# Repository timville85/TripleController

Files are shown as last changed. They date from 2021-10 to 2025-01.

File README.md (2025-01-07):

# 3dapter (formerly Triple Controller to USB)

This project combines the NES, SNES and Genesis DaemonBite Retro Controllers projects together with a custom PCB to support 3 different controllers with a single socketed Arduino Pro Micro. PCB (KiCad + Gerbers), 3D Cases, and muliple firmware versions (Arduino code) all available in this repository.

PCB Kits + Fully Assembled units (with firmware of your choice) available on [Tindie](https://www.tindie.com/products/24994/)

3 different firmware versions are available in this repo:
* Default: Optimized for MiSTer, PC, Raspberry Pi, etc. - reports as 3 separate controllers, supports multiplayer from a single unit.
* Analogue Pocket: Optimized for Pocket Dock - reports as a single wired XInput device.
* Nintendo Switch: Optimized for Nintendo Switch Online NES, SNES, and Genesis collections - reports as a single wired switch controller.

**Looking for a version with a N64 port? Check out the** [4dapter](https://github.com/timville85/4dapter)

## Resources Used

* [DaemonBite Retro Controllers](https://github.com/MickGyver/DaemonBite-Retro-Controllers-USB)
* https://github.com/esden/pretty-kicad-libs
* https://github.com/ddribin/nes-port-breadboard
* https://github.com/Biacco42/ProMicroKiCad
* http://www.neshq.com/hardgen/powerpad.txt

## 3D Case Files

3D Case files were designed by [Dinierto Designs](https://www.etsy.com/shop/DiniertoDesigns) and are available on [Thingiverse](https://www.thingiverse.com/thing:5011783)

3D Case Size Reference:
* 33mm - Most Micro USB Pro Micro / Sparkfun USB-C Pro Micro boards
* 35-36mm - Most AliExpress USB-C Pro Micro boards
* 36-37mm - Some AliExpress USB-C Pro Micro boards (typically with empty hole next to USB-C port)

## Wiring Diagram

TripleController-V2 1-Layout

Current Draw Readings from DIO Pin 16 (used for 5v supply for DB9 port):
* Krikzz Joyzz:	38mA
* 8BitDo M30 2.4G: 29mA
* OEM SEGA 3-Button Wired: 3mA
* OEM SEGA 6-Button Wired: 3mA
* Retrobit 6-Button Wired: 2mA
(Arduino DIO Max Rated Current: 40mA)

## Tested Controllers

The following controllers have been personally tested and are supported with the Triple Controller. All listed devices also fit when using the 3D Case as well.

NES:
* OEM NES Controller
* OEM NES PowerPad (Default FW Only)
* 8BitDo N30 2.4G Receiver
* 8BitDo NES Retro Receiver

SEGA / Genesis:
* OEM SEGA Master System 2-Button Controller
* OEM Genesis 3-Button Controller
* OEM Genesis 6-Button Controller
* 8BitDo M30 2.4G Receiver
* 8BitDo Genesis Retro Receiver
* Krikzz Joyzz

SNES:
* OEM SNES Controller
* OEM SFC Controller
* OEM SNES NTT Controller (Default FW Only)
* 8BitDo SN30 2.4G Receiver
* 8BitDo SNES Retro Receiver

## Bill of Materials
* **3dapter / Triple Controller PCB**

* **1x SNES Socket (90 deg):** [AliExpress - Gamers Zone Store](https://www.aliexpress.com/item/32838396935.html) 

* **1x NES Socket:** [AliExpress - Gamers Zone Store](https://www.aliexpress.com/item/1005003699734963.html)

* **1x Genesis Socket:** [AliExpress - Gamers Zone Store](https://www.aliexpress.com/item/1005003699497865.html)

* **Micro USB Arduino Pro Micro (reinforced USB port):** [Amazon](https://www.amazon.com/gp/product/B01HCXMBOU/) *(Pack of 3)*

* **1x Arduino Pro Micro (USB-C 3-15V Version):** [AliExpress](https://www.aliexpress.us/item/2251832700923799.html)

* **2x 1x12 Female Header:** [Digi-Key](https://www.digikey.com/en/products/detail/sullins-connector-solutions/PPTC121LFBN-RC/807231)

## PCB + Assembled Examples

unassembled

built

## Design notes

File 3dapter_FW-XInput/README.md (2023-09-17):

# 3dapter - XInput / Analogue Pocket Dock Firmware

This alternative firmware will allow the 3dapter (Triple Controller) to appear a single XInput controller. All 3 controller inputs will share the same singular player input (i.e. use only one controller at time). 

The controller inputs have been mapped to align with the default mapping on the Analogue Pocket Dock (as of firmware 1.1).

"Home" Button is supported on each controller type to bring up the Analogue Dock menu:
* NES: `Select + Down`
* SNES: `Select + Down`
* Genesis: `Mode + Down` (or 8BitDo M30 'Heart' button)

## IMPORTANT NOTE
**Installing the XInput Library will remove the self-reset listener from the Arduino board. This means you will need to manually reset the Arduino when updating the code on the board or switching to a different firmware.**

**You can accomplish this by connecting the RST and GND pins together - a tip of a screwdriver works well since the pins are next to each other.**



### Resources Used

* https://github.com/dmadison/ArduinoXInput
* https://github.com/dmadison/ArduinoXInput_AVR

## Install Instructions

**Instructions tested with Arduino 1.8.19 - not fully tested with Arduino 2.X!**

### 1. Install XInput Library (tested with 1.2.6) from Arduino Library Manager



### 2. Add the following URL as an Additional Board Manager URL (in File -> Preferences menu)

`https://raw.githubusercontent.com/dmadison/ArduinoXInput_Boards/master/package_dmadison_xinput_index.json`



### 3. Install XInput AVR Boards (tested with 1.0.5) from Arduino Boards Manager

_Note: Choose the AVR version, not Sparkfun_



### 4. Select "XInput AVR Boards - Arduino Leonardo w/ XInput" from Boards List



### 5. Download project to Arduino Pro Micro board

Remember after download your Arduino Pro Micro will no longer report as a Serial device and will not appear in the "Port" list in the Arduino software.

Note: If you are replacing existing code on the 3dapter, trigger the download from the Arduino software and then trigger a reset on the Arduino Pro Micro within a few seconds of starting the download. If the download fails initially due to not finding the COM port, repeat the download/reset process and it should work the second time.

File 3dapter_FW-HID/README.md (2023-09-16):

# 3dapter - HID Firmware for MiSTer / PC

The default HID firmware will allow the 3dapter (Triple Controller) to appear a multiplayer input controller with each controller input acting as it's own separate player/input.

## Controller Button Mapping

To maintain proper button mapping on MiSTer, it's recommended to map the SNES controller on the MiSTer Main menu and the NES / Genesis controllers will align to their core defaults properly.

```
Button   NES        SNES       GENESIS (normal)    GENESIS (MiSTer)
-------------------------------------------------------------------
01       B          B          B                   A 
02       A          A          A                   B
03       N/A        Y          Y                   X
04       N/A        X          X                   Y
05       N/A        L          Z                   Z
06       N/A        R          C                   C
07       SELECT     SELECT     MODE                MODE
08       START      START      START               START
09       N/A        N/A        HOME (8BitDo)       (N/A but HOME will send MODE + DOWN)
```

## MiSTer Home Menu Suggestion
* **NES:** SELECT + DOWN
* **SNES:** SELECT + DOWN
* **GENESIS:** MODE + DOWN

*Note: SELECT + DOWN = HOME on 8BitDo N30*

## MiSTer mode on 8bitdo M30 controller

The 3dapter exposes three "players" on one USB device.  Unfortunately MiSTer does not support setting keymaps per "player", MiSTer mode works around this by making sure the positional mapping is the same between all controllers.

MiSTer mode can be toggled on and off with "HOME + Z" (you have to press HOME first, Z second). This setting is saved to EEPROM and preserved across power cycles. The default is "normal mode".

When the Genesis controller is in MiSTer mode:

- The HOME button sends "DOWN + MODE" (This is because no equivalent of the HOME button exists on the other controller ports)

- Buttons are swapped: A with B and X with Y. This is such that the position of the buttons is consistent between SNES and Genesis.

## Retroarch Port Binding

Some Retroarch users have reported issues regarding setting the correct “Device Index” setting, since the 3dapter reports a single “device” to RetroArch with 3 different controllers, each as their own “index”.

In Retroarch, go to Settings → Input → Port 1 Binds → Device Index and then choose #3 for DB9 and presumably #1 or #2 for NES and SNES. Save and it sticks for that game, core or content directory.

https://retropie.org.uk/forum/topic/26681/port-binds/
https://retropie.org.uk/docs/RetroArch-Configuration/#core-input-remapping

## Install Instructions

### 1. Select "Arduino AVR Boards - Arduino Leonardo" from Boards List

### 2. Download project to Arduino Pro Micro board

## Restoring Firmware After Alternative Firmware Downloads

If you previously used the Analogue Pocket or Nintendo Switch firmware versions, your Arduino Pro Micro will no longer report as a Serial device and will not appear in the "Port" list in the Arduino software. Using the default 3dapter firmware does not suffer from this issue.

To restore the default firmware for your Arduino Pro Micro, you will need to manually reset the Arduino Pro Micro by shorting the Reset + Ground pins together to trigger a reset. 

1. Open the default firmware project in the Arduino software.
2. Connect your Arduino Pro Micro to your computer.
3. Trigger the download from the Arduino software. The Arduino software will first compile the project before beginning the download.
4. Once the "compiling" step has finished, trigger a reset on the Arduino Pro Micro by briefly touching the Reset (RST) and Ground (GND) pins together. This should make the Arduino forcefully switch into bootloader mode and allow the download to complete. If the download fails initially due to not finding the COM port, repeat the download/reset process and it should work the second time.

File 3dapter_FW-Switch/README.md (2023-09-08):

# 3dapter - Nintendo Switch Firmware

This alternative firmware will allow the 3dapter (Triple Controller) to appear a single Switch-compatible controller. All 3 controller inputs will share the same singular player input (i.e. use only one controller at time). 

The controller inputs have been mapped to align to map to the Nintendo Switch Virtual NES, SNES, and Genesis apps. Switch-specific button combos have been added to support in-game menus, home buttons, and screenshot capabities.

## IMPORTANT NOTE
**Installing the XInput Library will remove the self-reset listener from the Arduino board. This means you will need to manually reset the Arduino when updating the code on the board or switching to a different firmware.**

**You can accomplish this by connecting the RST and GND pins together - a tip of a screwdriver works well since the pins are next to each other.**



## Switch Special Button Combos

NES:
* In-Game Menu ("-" Button): Select + D-Pad Down
* Home Button: Select + Start
* Screenshot: Select + Up

SNES:
* In-Game Menu ("-" Button): Select + D-Pad Down
* Home Button: Select + Start
* Screenshot: Select + Up

Genesis (6-Button):
* In-Game Menu ("-" Button): Mode + Down
* Home Button: Mode + Start (or 8BitDo M30 Heart Button)
* Screenshot: Mode + D-Pad Up

Genesis (3-Button):
* In-Game Menu ("-" Button): Start + A + B + C
* Home Button: Start + A + Down
* Screenshot: Start + A + Up

Input Toggle to swap D-Pad Input / Left Analog Joystick
* Hold Select/Mode + Down for 1.5 seconds
* Reports 8-Way Input (Cardinal + Diagonal)

Input Toggle to swap X / RB buttons
* Hold Mode + B for 1.5 Seconds
* Useful for games within the "Sega Genesis Classics" collection

## Resources Used

* [LUFA Arduino Board & Library](https://github.com/CrazyRedMachine/Arduino-Lufa)
* [Switch-Fightstick](https://github.com/progmem/Switch-Fightstick).

## Install Instructions

### 1. Add the following URL as an Additional Board Manager URL (in File -> Preferences menu)
`https://github.com/CrazyRedMachine/Arduino-Lufa/raw/master/package_arduino-lufa_index.json`

### 2. Select and Install **`LUFA AVR Boards`** from the Arduino Board Manager

### 3. Select **`Arduino LUFA AVR Boards -> Arduino Leonardo (LUFA)`** from Boards list

### 4. Download project to Arduino Pro Micro board

Remember after download your Arduino Pro Micro will no longer report as a Serial device and will not appear in the "Port" list in the Arduino software.

Note: If you are replacing existing code on the 3dapter, trigger the download from the Arduino software and then trigger a reset on the Arduino Pro Micro within a few seconds of starting the download. If the download fails initially due to not finding the COM port, repeat the download/reset process and it should work the second time.

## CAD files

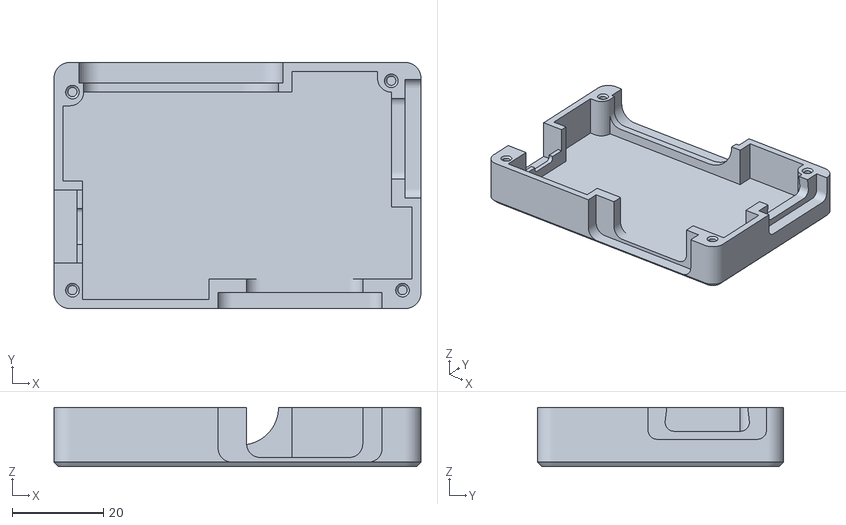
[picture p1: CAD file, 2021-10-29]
3dapter Cases/Micro USB (33mm)/3dapter - Micro USB (33mm) Top.stl
80.6 x 54.1 x 13.0

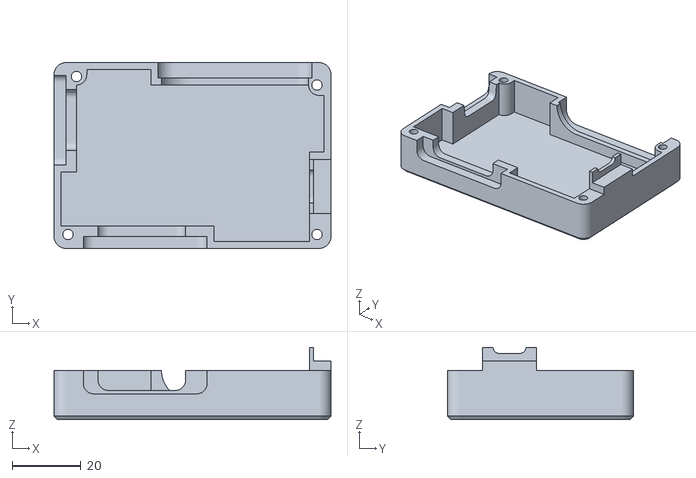
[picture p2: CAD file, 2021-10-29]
3dapter Cases/USB-C (33-34mm)/3dapter - USB-C (33-34mm) Bottom.stl
80.6 x 54.0 x 21.0

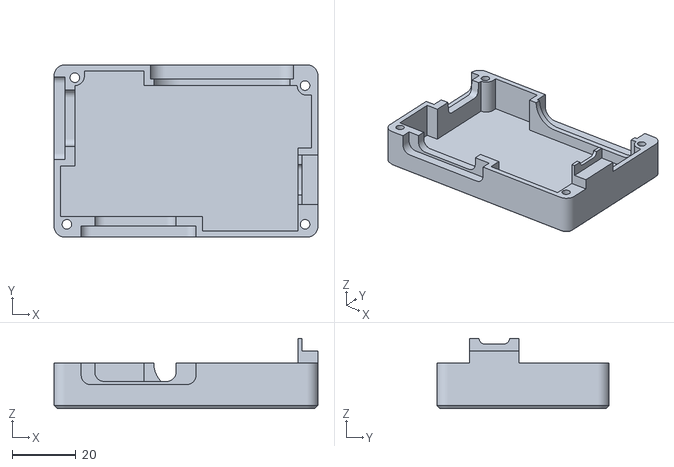
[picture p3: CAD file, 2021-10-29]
3dapter Cases/USB-C (35-36mm)/3dapter - USB-C (35-36mm) Bottom.stl
82.8 x 54.0 x 22.0

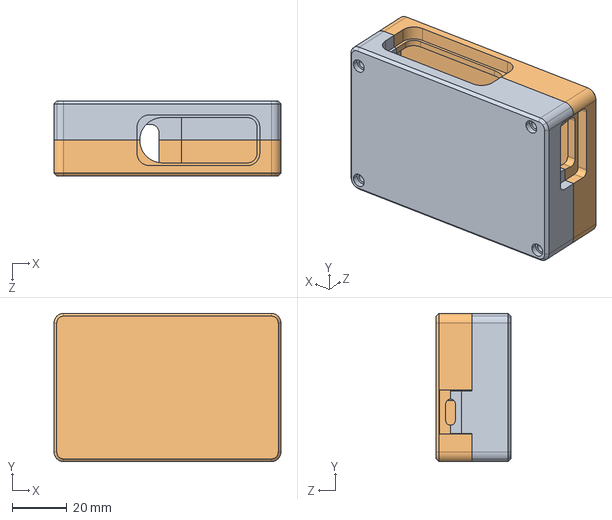
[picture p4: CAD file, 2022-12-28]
3dapter Cases/USB-C (36-37mm)/3dapter - USB-C (36-37mm).STEP
82.8 x 54.1 x 27.2 mm

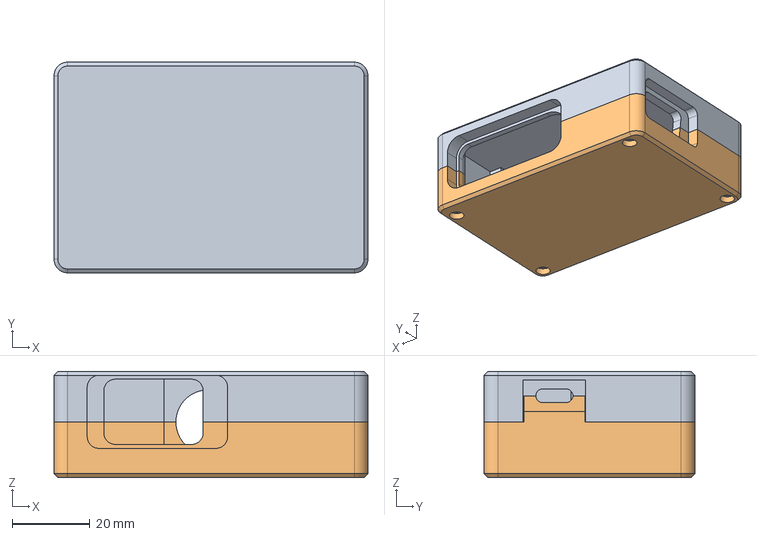
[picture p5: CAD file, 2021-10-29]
3dapter Cases/USB-C (33-34mm)/3dapter - USB-C (33-34mm).step
80.5 x 54.0 x 27.2 mm
Top
Bottom

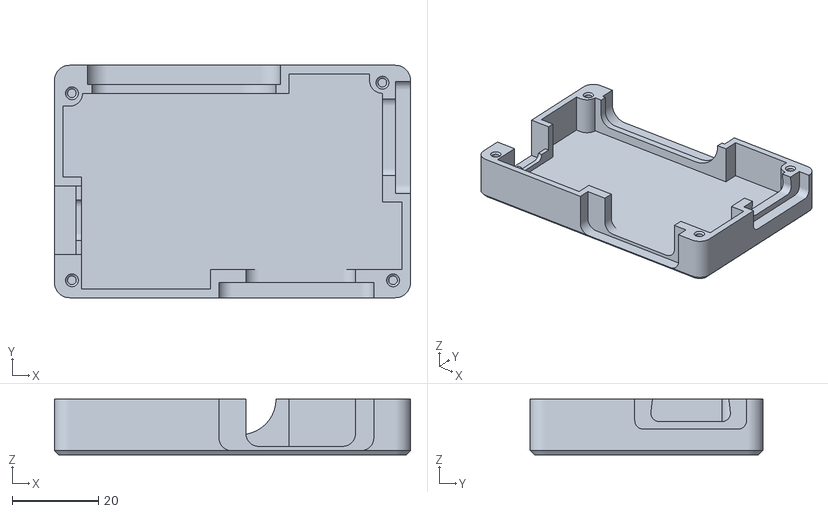
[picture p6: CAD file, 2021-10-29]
3dapter Cases/USB-C (35-36mm)/3dapter - USB-C (35-36mm) Top.stl
82.8 x 54.1 x 13.0

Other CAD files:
3dapter Cases/Micro USB (33mm)/3dapter - Micro USB (33mm) Bottom.stl
3dapter Cases/USB-C (35-36mm)/3dapter - USB-C (35-36mm).step
3dapter Cases/USB-C (36-37mm)/3dapter - USB-C (36-37mm) Bottom.STL
3dapter Cases/Micro USB (33mm)/3dapter - Micro USB (33mm).step
3dapter Cases/USB-C (33-34mm)/3dapter - USB-C (33-34mm) Top.stl
3dapter Cases/USB-C (36-37mm)/3dapter - USB-C (36-37mm) Top.STL

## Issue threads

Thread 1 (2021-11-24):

Not all buttons on all inputs work.

Numbski, 2021-11-24:
Using the Joystick Show app on Mac to test the triple input adapter, and it works 100% correctly with the SNES input.  The NES input, everything works correctly, except that Select and Start don't register as button presses.  Genesis is a bit more of a mess.

Down doesn't register at all.  Up and Left register as one axis, and right registers as another.  A button doesn't register, nor does start.  B and C work as-expected.  I don't have a Genesis 6-button controller to test with.  Using the latest github code as of this morning.

Numbski, 2021-11-24:
For hardware, I got two of the adapters from Tindie:

https://www.tindie.com/products/timville/triple-controller-classic-gaming-usb-adapter/

Using the 5v model Arduino Pro Micro from SparkFun.

Numbski, 2021-11-24:
Third party Genesis controller works as-expected, so perhaps my first party controller is somehow damaged.  Will investigate that further.

timville85, 2021-11-24:
I've found that 1st party female connectors can be a bit worn down and may not make as solid of a connection. You could try repositioning the pins inside of the DB9 port to make a tighter connection, or could also try replacing the OEM cable (if it's worn down) with one from Console5.

https://console5.com/store/atari-sega-commodore-coleco-msx-6-1-8m-joystick-controller-project-repair-cable-cord.html

For the NES issue, since it's a shift register and only a single data line, seems odd that it would register button presses but not start/stop. Start/Stop should register as buttons 7/8 (index 6/7) for the NES. I would try repositioning the controller a bit in the socket - see if not putting it all the way flush makes a difference.

Numbski, 2021-11-24:
Yeah, on a whim I tried other NES controllers, and some are okay, some Start/Select don't register, but they all work on an  actual NES.  I suspect it might be another variation on the same issue, but I will do some more testing.

At this point though, I think I can say with confidence that the issue on the NES isn't a code problem, as some do indeed work.  It may just be a connectivity one.  I no longer recall which shift registers select/start are on, but as it works on my SNES controllers, that likely isn't a code issue at all.

dubesinhower, 2021-11-26:
I'm having a similar problem with my original NES controllers. Won't register any inputs. But my 8BitDo NES adapter works fine

timville85, 2021-11-26:
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

The pins of the aftermarket connectors are not as large in diameter as the OEM pins on an NES console (as shown above). On more worn controllers plugs, the pins may not make solid connections, which would lead to the inconsistent performance.

A suggestion may be to slightly bend the pins in the aftermarket connector to try and make a better connection. I've tested quite a number of controllers and haven't found any issues with the 10+ that I've tested, so this is a hypothesis only at this point.

timville85, 2022-06-27:
Marking this one as closed for now as I've identified that some of the controller ports individual pins (mostly Genesis) may be below spec to get a reliable connection. I'm looking for these now when packing orders.

If you do ever experience this issue, you can try gently bending the pins to make better contact to see if that helps - if it doesn't, contact where you bought them (for me, via Tindie) for a replacement.

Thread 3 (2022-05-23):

Snes contoller error

When-Suddenly, 2022-05-23:
So basically I built this project a year ago, confirmed it working, got busy, and forgot about it until now. I only have 2 SNES controllers to test with this but was gaming fine in the past. Unfortunately, I am getting an error where no buttons work except the B button... and the B button inputs to all buttons except button 9. I re-tested all my leads and confirmed them working correctly, anyone know if there is a driver issue about this? Thanks for your time.

timville85, 2022-05-23:
Very strange for something to work for a while and then stop working without using it... Anything potentially shorted on the Arduino?

Have you tried the new V2 project? It's backwards compatible with V1 boards.

When-Suddenly, 2022-05-29:
sorry what is the V2 project? I am unaware of its existence

timville85, 2022-06-27:
V2 project is here:

https://github.com/timville85/TripleController/tree/main/TripleUSBController-V2.1

If you could capture a video of using the controller with some kind of display to show the buttons I could see what might be causing the issue (like the Windows Control Panel Game Controller display)

timville85, 2023-01-06:
Closing issue due to age. Feel free to reopen if needed.

Closed 2023-01-06.

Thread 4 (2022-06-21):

Error 302 when doing verify/compile

Veridor, 2022-06-21:
When tryig to update my board with the latest firmware, I first did a verify/compile in the Arduino IDE but I'm not getting a 302 error:

Arduino: 1.8.16 (Windows 10), Board: "SparkFun Pro Micro, ATmega32U4 (5V, 16 MHz)"

SegaController32U4.cpp:61:58: error: stray '\302' in program

   <title>TripleController/SegaController32U4.cpp at main · timville85/TripleController · GitHub</title>

                                                          ^

SegaController32U4.cpp:61:59: error: stray '\267' in program

   <title>TripleController/SegaController32U4.cpp at main · timville85/TripleController · GitHub</title>

                                                           ^

SegaController32U4.cpp:61:89: error: stray '\302' in program

   <title>TripleController/SegaController32U4.cpp at main · timville85/TripleController · GitHub</title>

                                                                                         ^

SegaController32U4.cpp:61:90: error: stray '\267' in program

   <title>TripleController/SegaController32U4.cpp at main · timville85/TripleController · GitHub</title>

                                                                                          ^

Gamepad.cpp:61:47: error: stray '\302' in program

   <title>TripleController/Gamepad.cpp at main · timville85/TripleController · GitHub</title>

                                               ^

Gamepad.cpp:61:48: error: stray '\267' in program

   <title>TripleController/Gamepad.cpp at main · timville85/TripleController · GitHub</title>

                                                ^

Gamepad.cpp:61:78: error: stray '\302' in program

   <title>TripleController/Gamepad.cpp at main · timville85/TripleController · GitHub</title>

                                                                              ^

Gamepad.cpp:61:79: error: stray '\267' in program

   <title>TripleController/Gamepad.cpp at main · timville85/TripleController · GitHub</title>

                                                                               ^

SegaController32U4.cpp:418:10: error: missing terminating ' character

     <!-- '"` --><!-- </textarea></xmp> --></option></form><form class="js-site-search-form" role="search" aria-label="Site" data-scope-type="Repository" data-scope-id="397431487" data-scoped-search-url="/timville85/TripleController/search" data-owner-scoped-search-url="/users/timville85/search" data-unscoped-search-url="/search" data-turbo="false" action="/timville85/TripleController/search" accept-charset="UTF-8" method="get">

          ^~~~~~~~~~~~~~~~~~~~~~~~~~~~~~~~~~~~~~~~~~~~~~~~~~~~~~~~~~~~~~~~~~~~~~~~~~~~~~~~~~~~~~~~~~~~~~~~~~~~~~~~~~~~~~~~~~~~~~~~~~~~~~~~~~~~~~~~~~~~~~~~~~~~~~~~~~~~~~~~~~~~~~~~~~~~~~~~~~~~~~~~~~~~~~~~~~~~~~~~~~~~~~~~~~~~~~~~~~~~~~~~~~~~~~~~~~~~~~~~~~~~~~~~~~~~~~~~~~~~~~~~~~~~~~~~~~~~~~~~~~~~~~~~~~~~~~~~~~~~~~~~~~~~~~~~~~~~~~~~~~~~~~~~~~~~~~~~~~~~~~~~~~~~~~~~~~~~~~~~~~~~~~~~~~~~~~~~~~~~~~~~~~~~~~~~~~~~~~~~~~~~~~~~~~~~~~~~~~~~~~

Gamepad.cpp:418:10: error: missing terminating ' character

     <!-- '"` --><!-- </textarea></xmp> --></option></form><form class="js-site-search-form" role="search" aria-label="Site" data-scope-type="Repository" data-scope-id="397431487" data-scoped-search-url="/timville85/TripleController/search" data-owner-scoped-search-url="/users/timville85/search" data-unscoped-search-url="/search" data-turbo="false" action="/timville85/TripleController/search" accept-charset="UTF-8" method="get">

          ^~~~~~~~~~~~~~~~~~~~~~~~~~~~~~~~~~~~~~~~~~~~~~~~~~~~~~~~~~~~~~~~~~~~~~~~~~~~~~~~~~~~~~~~~~~~~~~~~~~~~~~~~~~~~~~~~~~~~~~~~~~~~~~~~~~~~~~~~~~~~~~~~~~~~~~~~~~~~~~~~~~~~~~~~~~~~~~~~~~~~~~~~~~~~~~~~~~~~~~~~~~~~~~~~~~~~~~~~~~~~~~~~~~~~~~~~~~~~~~~~~~~~~~~~~~~~~~~~~~~~~~~~~~~~~~~~~~~~~~~~~~~~~~~~~~~~~~~~~~~~~~~~~~~~~~~~~~~~~~~~~~~~~~~~~~~~~~~~~~~~~~~~~~~~~~~~~~~~~~~~~~~~~~~~~~~~~~~~~~~~~~~~~~~~~~~~~~~~~~~~~~~~~~~~~~~~~~~~~~~~~

SegaController32U4.cpp:475:75: error: stray '\342' in program

       <span aria-hidden="true" class="d-inline-block ml-1 v-align-middle">↵</span>

                                                                           ^

SegaController32U4.cpp:475:76: error: stray '\206' in program

       <span aria-hidden="true" class="d-inline-block ml-1 v-align-middle">↵</span>

                                                                            ^

SegaController32U4.cpp:475:77: error: stray '\265' in program

       <span aria-hidden="true" class="d-inline-block ml-1 v-align-middle">↵</span>

                                                                             ^

Gamepad.cpp:475:75: error: stray '\342' in program

       <span aria-hidden="true" class="d-inline-block ml-1 v-align-middle">↵</span>

                                                                           ^

SegaController32U4.cpp:480:56: error: stray '\342' in program

       <span class="d-inline-block ml-1 v-align-middle">↵</span>

                                                        ^

Gamepad.cpp:475:76: error: stray '\206' in program

       <span aria-hidden="true" class="d-inline-block ml-1 v-align-middle">↵</span>

                                                                            ^

SegaController32U4.cpp:480:57: error: stray '\206' in program

       <span class="d-inline-block ml-1 v-align-middle">↵</span>

                                                         ^

SegaController32U4.cpp:480:58: error: stray '\265' in program

       <span class="d-inline-block ml-1 v-align-middle">↵</span>

                                                          ^

Gamepad.cpp:475:77: error: stray '\265' in program

       <span aria-hidden="true" class="d-inline-block ml-1 v-align-middle">↵</span>

                                                                             ^

Gamepad.cpp:480:56: error: stray '\342' in program

       <span class="d-inline-block ml-1 v-align-middle">↵</span>

                                                        ^

SegaController32U4.cpp:522:75: error: stray '\342' in program

       <span aria-hidden="true" class="d-inline-block ml-1 v-align-middle">↵</span>

                                                                           ^

Gamepad.cpp:480:57: error: stray '\206' in program

       <span class="d-inline-block ml-1 v-align-middle">↵</span>

                                                         ^

Gamepad.cpp:480:58: error: stray '\265' in program

       <span class="d-inline-block ml-1 v-align-middle">↵</span>

                                                          ^

SegaController32U4.cpp:522:76: error: stray '\206' in program

       <span aria-hidden="true" class="d-inline-block ml-1 v-align-middle">↵</span>

                                                                            ^

Gamepad.cpp:522:75: error: stray '\342' in program

       <span aria-hidden="true" class="d-inline-block ml-1 v-align-middle">↵</span>

                                                                           ^

SegaController32U4.cpp:522:77: error: stray '\265' in program

       <span aria-hidden="true" class="d-inline-block ml-1 v-align-middle">↵</span>

                                                                             ^

Gamepad.cpp:522:76: error: stray '\206' in program

       <span aria-hidden="true" class="d-inline-block ml-1 v-align-middle">↵</span>

                                                                            ^

SegaController32U4.cpp:527:56: error: stray '\342' in program

       <span class="d-inline-block ml-1 v-align-middle">↵</span>

                                                        ^

Gamepad.cpp:522:77: error: stray '\265' in program

       <span aria-hidden="true" class="d-inline-block ml-1 v-align-middle">↵</span>

                                                                             ^

SegaController32U4.cpp:527:57: error: stray '\206' in program

       <span class="d-inline-block ml-1 v-align-middle">↵</span>

                                                         ^

Gamepad.cpp:527:56: error: stray '\342' in program

       <span class="d-inline-block ml-1 v-align-middle">↵</span>

                                                        ^

SegaController32U4.cpp:527:58: error: stray '\265' in program

       <span class="d-inline-block ml-1 v-align-middle">↵</span>

                                                          ^

Gamepad.cpp:527:57: error: stray '\206' in program

       <span class="d-inline-block ml-1 v-align-middle">↵</span>

                                                         ^

SegaController32U4.cpp:560:75: error: stray '\342' in program

       <span aria-hidden="true" class="d-inline-block ml-1 v-align-middle">↵</span>

                                                                           ^

Gamepad.cpp:527:58: error: stray '\265' in program

       <span class="d-inline-block ml-1 v-align-middle">↵</span>

                                                          ^

SegaController32U4.cpp:560:76: error: stray '\206' in program

       <span aria-hidden="true" class="d-inline-block ml-1 v-align-middle">↵</span>

                                                                            ^

SegaController32U4.cpp:560:77: error: stray '\265' in program

       <span aria-hidden="true" class="d-inline-block ml-1 v-align-middle">↵</span>

                                                                             ^

Gamepad.cpp:560:75: error: stray '\342' in program

       <span aria-hidden="true" class="d-inline-block ml-1 v-align-middle">↵</span>

                                                                           ^

SegaController32U4.cpp:565:56: error: stray '\342' in program

       <span class="d-inline-block ml-1 v-align-middle">↵</span>

                                                        ^

Gamepad.cpp:560:76: error: stray '\206' in program

       <span aria-hidden="true" class="d-inline-block ml-1 v-align-middle">↵</span>

                                                                            ^

SegaController32U4.cpp:565:57: error: stray '\206' in program

       <span class="d-inline-block ml-1 v-align-middle">↵</span>

                                                         ^

Gamepad.cpp:560:77: error: stray '\265' in program

       <span aria-hidden="true" class="d-inline-block ml-1 v-align-middle">↵</span>

                                                                             ^

SegaController32U4.cpp:565:58: error: stray '\265' in program

       <span class="d-inline-block ml-1 v-align-middle">↵</span>

                                                          ^

Gamepad.cpp:565:56: error: stray '\342' in program

       <span class="d-inline-block ml-1 v-align-middle">↵</span>

                                                        ^

SegaController32U4.cpp:598:75: error: stray '\342' in program

       <span aria-hidden="true" class="d-inline-block ml-1 v-align-middle">↵</span>

                                                                           ^

Gamepad.cpp:565:57: error: stray '\206' in program

       <span class="d-inline-block ml-1 v-align-middle">↵</span>

                                                         ^

SegaController32U4.cpp:598:76: error: stray '\206' in program

       <span aria-hidden="true" class="d-inline-block ml-1 v-align-middle">↵</span>

                                                                            ^

Gamepad.cpp:565:58: error: stray '\265' in program

       <span class="d-inline-block ml-1 v-align-middle">↵</span>

                                                          ^

SegaController32U4.cpp:598:77: error: stray '\265' in program

       <span aria-hidden="true" class="d-inline-block ml-1 v-align-middle">↵</span>

                                                                             ^
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

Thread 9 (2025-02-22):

Arduino FW 'no Lufa.h'  found

Slypty, 2025-02-22:
Maybe I'm at fault, but after doing a complete proper reinstall of Arduino IDE, I'm still getting the following message from Arduino when I try to program the Micro:

C:\Users\Willbot\Documents\Arduino\libraries\TripleController-main\TripleController-main\3dapter_FW-Switch\SegaController32U4.cpp:31:10: fatal error: EEPROM.h: No such file or directory
 #include <EEPROM.h>
          ^~~~~~~~~~
compilation terminated.
exit status 1

Compilation error: EEPROM.h: No such file or directory

timville85, 2025-02-23:
Just tried it on my install on Arduino 1.8.19 and it's building OK - have you selected the correct board type?

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

I have not tested it on Arduino 2.X

Slypty, 2025-02-23:
Thanks, I have the AVR Boards and LUFA Leopard as the selected Board.  Before I installed to the most recent IDE, the headr <LUFA.h> wasn't being found.  There seems to always be a .h type file that goes amiss, maybe Arduino reorganized the folders over the years.  I might try a legacy version and report back.

Slypty, 2025-02-24:
I installed 1.8.19 on a different PC, uploaded the .json and installed the AVR boards.  I get the same no 'Lufa.h' found error.  Within the Switch FW folder, there is no Lufa.h file, but there is a Lufa.c.
The other header files seem to all be in the Switch FW folder, so I'm uncertain where to find Lufa.h?  Is it missing from the Switch FW, or does Arduino put it in to some folder and I need to copy it over?
I am using User/Documents/Arduino to Store the Triple Controller folder.

timville85, 2025-02-24:
I just tried everything on a clean Windows 11 machine with a clean Arduino 1.8.19 install.

I only had to add the boards JSON, install the LUFA AVR Boards 0.93.0 version, select Arduino Leonardo (LUFA) as the board type, and then compile the project (which was on my Desktop in the structure of the GitHub ZIP folder). Everything compiled without issue.

I'm not sure if it's a permissions issue, but the Lufa.h file is what comes with the boards installation, so it's not included with the project. But I can't seem to recreate this issue at the moment.

Slypty, 2025-02-24:
Ok thanks for helping.  I'll wait for another ATMegu32U4 to be shipped and retry, it should be working and doesn't seem like a common error, so maybe I have a software bug of some sort.

timville85, 2025-02-24:
I don't think it'll be anything related to the hardware - it should be compiling (building) without any hardware attached.

Maybe try enabling verbose logging for compilation:
https://support.arduino.cc/hc/en-us/articles/4407705216274-Use-verbose-output-in-the-Arduino-IDE

Then post your output here and maybe I can help (or someone else looking) might be able to point out where the issue is.

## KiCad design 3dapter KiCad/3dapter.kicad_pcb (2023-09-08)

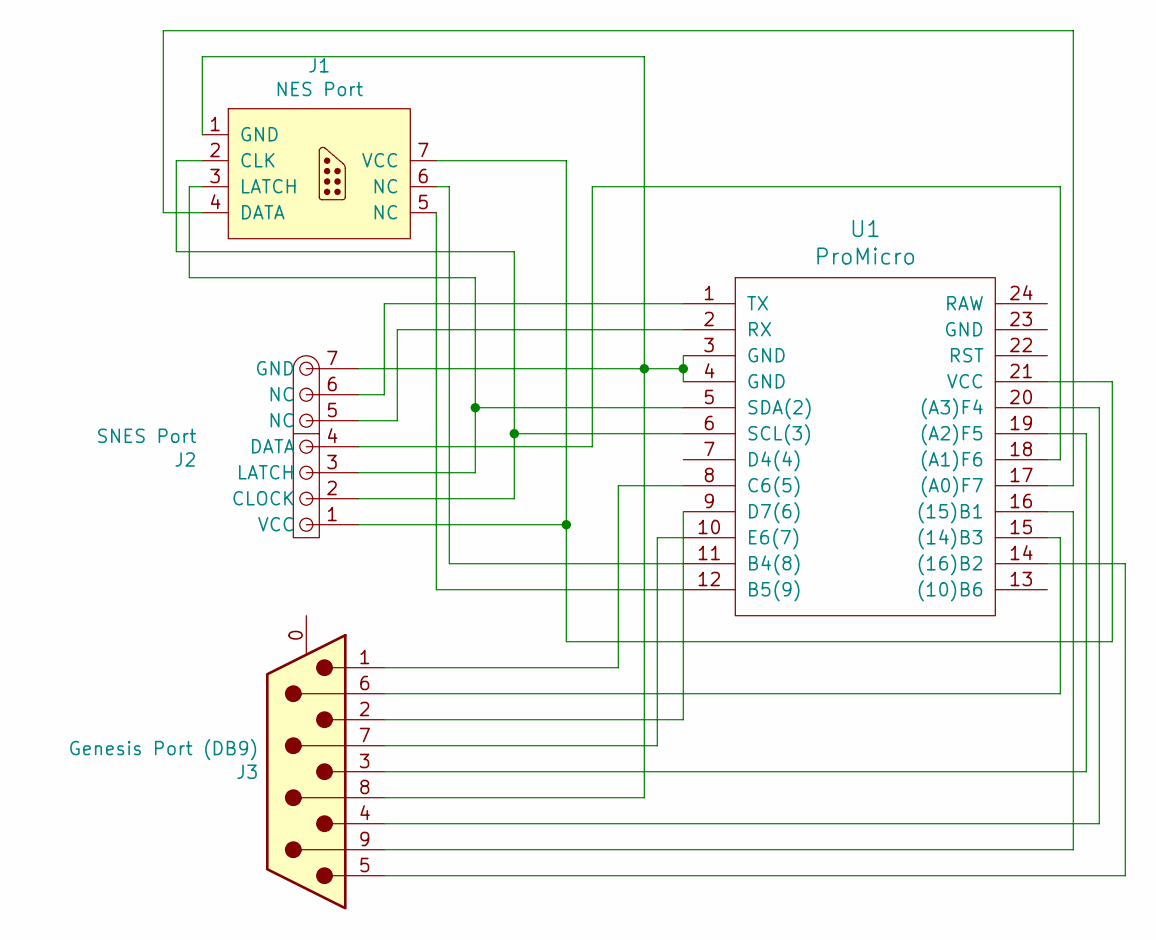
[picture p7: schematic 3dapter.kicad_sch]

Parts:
J1: NES Port; NES
J2: SNES Port; SNES
J3: Genesis Port (DB9); DSUB-9_Male_Horizontal_P2.77x2.54mm_EdgePinOffset9.40mm
U1: ProMicro

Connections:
unnamed: J1.1 (GND), J2.7 (GND), J3.8, U1.3 (GND), U1.4 (GND)
unnamed: J1.2 (CLK), J2.2 (CLOCK), U1.6 (SCL(3))
unnamed: J1.3 (LATCH), J2.3 (LATCH), U1.5 (SDA(2))
unnamed: J1.4 (DATA), U1.17 ((A0)F7)
unnamed: J1.5 (NC), U1.12 (B5(9))
unnamed: J1.6 (NC), U1.11 (B4(8))
unnamed: J1.7 (VCC), J2.1 (VCC), U1.21 (VCC)
unnamed: J2.4 (DATA), U1.18 ((A1)F6)
unnamed: J2.5 (NC), U1.2 (RX)
unnamed: J2.6 (NC), U1.1 (TX)
unnamed: J3.1, U1.8 (C6(5))
unnamed: J3.2, U1.9 (D7(6))
unnamed: J3.3, U1.19 ((A2)F5)
unnamed: J3.4, U1.20 ((A3)F4)
unnamed: J3.5, U1.14 ((16)B2)
unnamed: J3.6, U1.15 ((14)B3)
unnamed: J3.7, U1.10 (E6(7))
unnamed: J3.9, U1.16 ((15)B1)

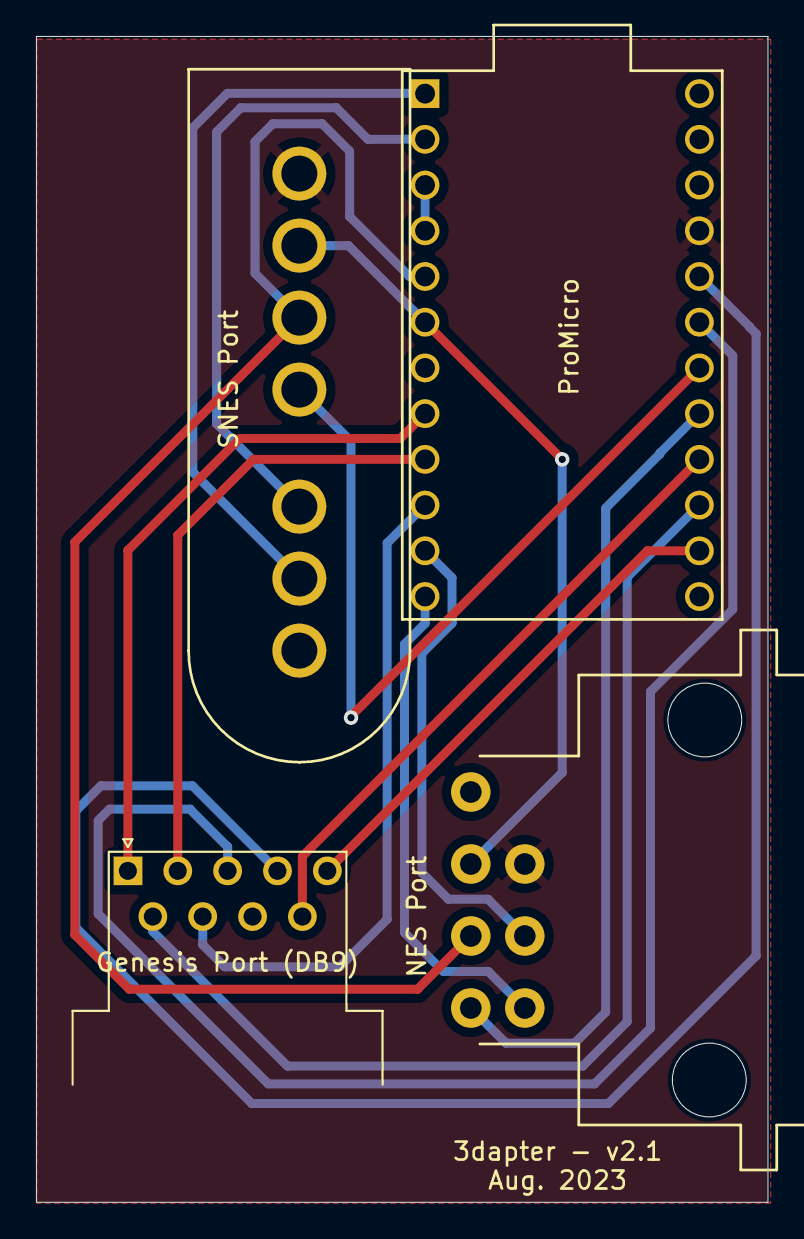
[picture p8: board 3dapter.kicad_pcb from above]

Board: 2 copper layers, 40.6 x 64.8 mm, 4 parts (0 on the bottom side), 18 nets.

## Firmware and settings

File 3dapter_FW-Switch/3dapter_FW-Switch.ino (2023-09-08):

#include "LUFAConfig.h"
#include <LUFA.h>
#include "Joystick.h"
#include "SegaController32U4.h"

uint32_t buttonStatus[18];

#define DPAD_UP_MASK_ON         0x00
#define DPAD_UPRIGHT_MASK_ON    0x01
#define DPAD_RIGHT_MASK_ON      0x02
#define DPAD_DOWNRIGHT_MASK_ON  0x03
#define DPAD_DOWN_MASK_ON       0x04
#define DPAD_DOWNLEFT_MASK_ON   0x05
#define DPAD_LEFT_MASK_ON       0x06
#define DPAD_UPLEFT_MASK_ON     0x07
#define DPAD_NOTHING_MASK_ON    0x08

#define Y_MASK_ON         0x01
#define B_MASK_ON         0x02
#define A_MASK_ON         0x04
#define X_MASK_ON         0x08
#define LB_MASK_ON        0x10
#define RB_MASK_ON        0x20
#define ZL_MASK_ON        0x40
#define ZR_MASK_ON        0x80
#define SELECT_MASK_ON    0x100
#define START_MASK_ON     0x200
#define L3_MASK_ON        0x400
#define R3_MASK_ON        0x800
#define HOME_MASK_ON      0x1000
#define CAPTURE_MASK_ON   0x2000

#define BUTTONUP      0
#define BUTTONDOWN    1
#define BUTTONLEFT    2
#define BUTTONRIGHT   3
#define BUTTONA       4
#define BUTTONB       5
#define BUTTONX       6
#define BUTTONY       7
#define BUTTONLB      8
#define BUTTONRB      9
#define BUTTONLT      10
#define BUTTONRT      11
#define BUTTONSTART   12
#define BUTTONSELECT  13
#define BUTTONHOME    14
#define BUTTONCAPTURE 15
#define BUTTONL3      16
#define BUTTONR3      17

#define NES       0
#define SNES      1
#define GENESIS   2

#define BUTTONS   0
#define AXES      1

#define UP        0x01
#define DOWN      0x02
#define LEFT      0x04
#define RIGHT     0x08

#define NTT_BIT   0x00
#define NODATA    0x00

long LeftX = 0;
long LeftY = 0;
long RightX = 0;
long RightY = 0;

bool Swap_DPAD_JOY = false;
bool Swap_Gen_Button = false;
#define toggleDelay 1500

void sendLatch();
void sendClock();
void sendState();
void processInputs();

// Manage EEPROM by making sure everything has
// its own index.
enum EEPROMIndices { GENESIS_EEPROM };

// Set up USB HID gamepads
SegaController32U4  gen_controller(GENESIS_EEPROM);

// Controllers
uint32_t  controllerData[2][2]  = {{0,0},{0,0}};
uint32_t  axisIndicator[32]     = {0,0,0,0,1,1,1,1,0,0,0,0,0,0,0,0,0,0,0,0,0,0,0,0,0,0,0,0,0,0,0,0};
uint16_t  currentGenesisState   = 0;
bool      nttActive             = false;

uint32_t  dataMaskNES[8] =        {0x02,   // A
                                   0x01,   // B
                                   0x40,   // Start 
                                   0x80,   // Select
                                   UP,     // D-Up
                                   DOWN,   // D-Down
                                   LEFT,   // D-Left
                                   RIGHT   // D-Right
                                   }; 

// Power Pad D4
uint32_t  dataMaskPowerPadD4[8] = {0x08,    // PowerPad #4
                                   0x04,    // PowerPad #3
                                   0x800,   // PowerPad #12
                                   0x80,    // PowerPad #8
                                   NODATA,  // No Data
                                   NODATA,  // No Data
                                   NODATA,  // No Data
                                   NODATA   // No Data
                                   }; 

// Power Pad D3
uint32_t  dataMaskPowerPadD3[8] = {0x02,   // PowerPad #2
                                   0x01,   // PowerPad #1
                                   0x10,   // PowerPad #5
                                   0x100,  // PowerPad #9
                                   0x20,   // PowerPad #6
                                   0x200,  // PowerPad #10
                                   0x400,  // PowerPad #11
                                   0x40    // PowerPad #7
                                   }; 

uint32_t  dataMaskSNES[32] =      {0x01,    // B
                                   0x04,    // Y
                                   0x40,    // Start   
                                   0x80,    // Select
                                   UP,      // D-Up
                                   DOWN,    // D-Down
                                   LEFT,    // D-Left
                                   RIGHT,   // D-Right
                                   0x02,    // A
                                   0x08,    // X
                                   0x10,    // L
                                   0x20,    // R
                                   NODATA,  // SNES Control Bit
                                   NTT_BIT, // NTT Indicator Bit
                                   NODATA,  // SNES Control Bit
                                   NODATA,  // SNES Control Bit
                                   0x100,   // NTT 0
                                   0x200,   // NTT 1
                                   0x400,   // NTT 2
                                   0x800,   // NTT 3
                                   0x1000,  // NTT 4
                                   0x2000,  // NTT 5
                                   0x4000,  // NTT 6
                                   0x8000,  // NTT 7
                                   0x10000, // NTT 8
                                   0x20000, // NTT 9
                                   0x40000, // NTT *
                                   0x80000, // NTT #
                                   0x100000,// NTT .
                                   0x200000,// NTT C
                                   NODATA,  // NTT No Data
                                   0x800000,// NTT End Comms
                                   };

void setup() 
{
  // Pin 4 Toggle Switch
  DDRD  &= ~B00010000; // inputs
  PORTD |=  B00010000; // enable internal pull-ups

  // On Board TX LED
  DDRD  |= B00100000; // output
  PORTD |= B00100000; // high

  // On Board RX LED
  DDRB  |= B00000001; // output
  PORTB |= B00000001; // high
  
  // Setup NES / SNES latch and clock pins (2/3 or PD1/PD0)
  DDRD  |=  B00000011; // output
  PORTD &= ~B00000011; // low

  // Setup NES / SNES data pins (A0/A1 or PF6/PF7)
  DDRF  &= ~B11000000; // inputs
  PORTF |=  B11000000; // enable internal pull-ups

  // Setup NES PowerPad data pins (8/9 or PB4/PB5)
  DDRB  &= ~B00110000; // inputs
  PORTB |=  B00110000; // enable internal pull-ups

  // Setup power pin (DB9 Pin 5) as output high (PB2)
  DDRB  |= B00000100; // output
  PORTB |= B00000100; // high
  
  SetupHardware();
  GlobalInterruptEnable();
}

void loop() 
{   
    currentGenesisState = 0;
    
    //8 cycles needed to capture 6-button controllers
    for(uint8_t i = 0; i < 8; i++)
    {
      currentGenesisState = gen_controller.updateState();
    }

    currentGenesisState = gen_controller.getFinalState();
    
    for(uint8_t j = 0; j < 1; j++)
    {
      sendLatch();

      controllerData[NES][BUTTONS] = 0;
      controllerData[NES][AXES] = 0;
      
      controllerData[SNES][BUTTONS] = 0;
      controllerData[SNES][AXES] = 0;

      nttActive = false;
  
      for(uint8_t dataBitCounter = 0; dataBitCounter < 32; dataBitCounter++)
      {
        // If no NTT controller, end the loop early
        if(!nttActive && dataBitCounter > 13)
        {
          break;
        }

        //NES Power Pad Controller
        if((dataBitCounter < 8) && ((PINB & B00100000) == 0)) //Power Pad Pin D4 (bottom)
        { 
          controllerData[NES][BUTTONS] |= dataMaskPowerPadD4[dataBitCounter];
        }

        if((dataBitCounter < 8) && ((PINB & B00010000) == 0)) //Power Pad Pin D3 (middle)
        { 
          controllerData[NES][BUTTONS] |= dataMaskPowerPadD3[dataBitCounter];
        }

        // NES Controller
        if((dataBitCounter < 8) && ((PINF & B10000000) == 0)) //If NES data line is low (indicating a press)
        { 
          if(axisIndicator[dataBitCounter])
          {
            controllerData[NES][AXES] |= dataMaskNES[dataBitCounter];
          }
          else
          {
            controllerData[NES][BUTTONS] |= dataMaskNES[dataBitCounter];
          }
        }

        // SNES / NTT Controller 
        if((PINF & B01000000) == 0) //If SNES data line is low (indicating a press)
        {
          if(dataBitCounter == 13)
          {
            nttActive = true;
          }
          
          if(axisIndicator[dataBitCounter])
          {
            controllerData[SNES][AXES] |= dataMaskSNES[dataBitCounter];
          }
          else
          {
            controllerData[SNES][BUTTONS] |= dataMaskSNES[dataBitCounter];
          }
        }
        
        sendClock();
      }
    }

  __builtin_avr_delay_cycles(1000);
  
  sendState();
}

void sendState()
{
  buttonRead();
  processInputs();
  HID_Task();
  USB_USBTask();
}

void sendLatch()
{
  // Send a latch pulse to NES/SNES
  PORTD |=  B00000010; // Set HIGH
  __builtin_avr_delay_cycles(192);
  PORTD &= ~B00000010; // Set LOW
  __builtin_avr_delay_cycles(72);
}

void sendClock()
{
  // Send a clock pulse to NES/SNES
  PORTD |=  B00000001; // Set HIGH
  __builtin_avr_delay_cycles(96);
  PORTD &= ~B00000001; // Set LOW
  __builtin_avr_delay_cycles(72);
}

void buttonRead()
{
  buttonStatus[BUTTONUP]      = (controllerData[NES][AXES] & UP)          |  (controllerData[SNES][AXES] & UP)          | ((currentGenesisState & SC_BTN_UP) >> SC_BIT_SH_UP);
  buttonStatus[BUTTONDOWN]    = ((controllerData[NES][AXES] & DOWN) >> 1)  | ((controllerData[SNES][AXES] & DOWN) >> 1)  | ((currentGenesisState & SC_BTN_DOWN) >> SC_BIT_SH_DOWN);
  buttonStatus[BUTTONLEFT]    = ((controllerData[NES][AXES] & LEFT) >> 2)  | ((controllerData[SNES][AXES] & LEFT) >> 2)  | ((currentGenesisState & SC_BTN_LEFT) >> SC_BIT_SH_LEFT);
  buttonStatus[BUTTONRIGHT]   = ((controllerData[NES][AXES] & RIGHT) >> 3) | ((controllerData[SNES][AXES] & RIGHT) >> 3) | ((currentGenesisState & SC_BTN_RIGHT) >> SC_BIT_SH_RIGHT);
  buttonStatus[BUTTONA]       = (controllerData[NES][BUTTONS] & 0x02 ? 1:0) | (controllerData[SNES][BUTTONS] & 0x02 ? 1:0) | (currentGenesisState & SC_BTN_C ? 1:0);
  
  if(Swap_Gen_Button)
  {
    buttonStatus[BUTTONRB]      = (controllerData[SNES][BUTTONS] & 0x20) | (currentGenesisState & SC_BTN_Y ? 1:0);
    buttonStatus[BUTTONB]       = (controllerData[NES][BUTTONS] & 0x01 ? 1:0) | (controllerData[SNES][BUTTONS] & 0x01 ? 1:0) | (currentGenesisState & SC_BTN_B ? 1:0);
    buttonStatus[BUTTONX]       = (controllerData[SNES][BUTTONS] & 0x08) | (currentGenesisState & SC_BTN_Z ? 1:0);
  }
  else
  {
    buttonStatus[BUTTONRB]      = (controllerData[SNES][BUTTONS] & 0x20) | (currentGenesisState & SC_BTN_Z ? 1:0);
    buttonStatus[BUTTONB]       = (controllerData[NES][BUTTONS] & 0x01 ? 1:0) | (controllerData[SNES][BUTTONS] & 0x01 ? 1:0) | (currentGenesisState & SC_BTN_B ? 1:0);
    buttonStatus[BUTTONX]       = (controllerData[SNES][BUTTONS] & 0x08) | (currentGenesisState & SC_BTN_Y ? 1:0);
  }
  
  buttonStatus[BUTTONY]       = (controllerData[SNES][BUTTONS] & 0x04) | (currentGenesisState & SC_BTN_A ? 1:0);
  buttonStatus[BUTTONLB]      = (controllerData[SNES][BUTTONS] & 0x10) | (currentGenesisState & SC_BTN_X ? 1:0);
  buttonStatus[BUTTONLT]      = 0;
  buttonStatus[BUTTONRT]      = 0;
  buttonStatus[BUTTONSTART]   = (controllerData[NES][BUTTONS] & 0x80) | (controllerData[SNES][BUTTONS] & 0x80) | (currentGenesisState & SC_BTN_START ? 1:0);
  buttonStatus[BUTTONSELECT]  = (controllerData[NES][BUTTONS] & 0x40) | (controllerData[SNES][BUTTONS] & 0x40) | (currentGenesisState & SC_BTN_MODE ? 1:0);
  buttonStatus[BUTTONHOME]    = (currentGenesisState & SC_BTN_HOME ? 1:0);
  buttonStatus[BUTTONCAPTURE] = 0;
  buttonStatus[BUTTONL3]      = 0;
  buttonStatus[BUTTONR3]      = 0;

  //////////////////////////////////////////////

  toggleControls();

  /////////////////////////////////////////////

  // NES - SNES - Genesis: Home Command (Select/Mode + Start)
  if(buttonStatus[BUTTONSELECT] && buttonStatus[BUTTONSTART])  
  {
    buttonStatus[BUTTONSTART]   = 0;
    buttonStatus[BUTTONSELECT]  = 0;
    buttonStatus[BUTTONHOME]    = 1;
  }

  // NES - SNES - Genesis: In-Game Menu Command (Select/Mode + D-Down)
  if(buttonStatus[BUTTONSELECT] && buttonStatus[BUTTONDOWN])
  {
    buttonStatus[BUTTONSELECT]  = 0;
    buttonStatus[BUTTONDOWN]    = 0;
    buttonStatus[BUTTONLT]      = 1;
    buttonStatus[BUTTONRT]      = 1;
  }

  // NES - SNES - Genesis: Screenshot Command (Select/Mode + D-Up)
  if(buttonStatus[BUTTONSELECT] && buttonStatus[BUTTONUP])  
  {
    buttonStatus[BUTTONUP]      = 0;
    buttonStatus[BUTTONSELECT]  = 0;
    buttonStatus[BUTTONCAPTURE] = 1;
  }

  /////////////////////////////////////////////

  // Genesis 3-Button: In-Game Menu Command (A + B + C + Start)
  if((!gen_controller.sixButtonMode) && (currentGenesisState & SC_BTN_START ? 1:0) && (currentGenesisState & SC_BTN_A ? 1:0) && (currentGenesisState & SC_BTN_B ? 1:0) && (currentGenesisState & SC_BTN_C ? 1:0))
  {
    buttonStatus[BUTTONSTART] = 0;
    buttonStatus[BUTTONY]     = 0;
    buttonStatus[BUTTONB]     = 0;
    buttonStatus[BUTTONA]     = 0;
    buttonStatus[BUTTONLT]    = 1;
    buttonStatus[BUTTONRT]    = 1;
  }

  // Genesis 3-Button: Home Command (A + D-Down + Start)
  if((!gen_controller.sixButtonMode) && (currentGenesisState & SC_BTN_START ? 1:0) && (currentGenesisState & SC_BTN_A ? 1:0) && ((currentGenesisState & SC_BTN_DOWN) >> SC_BIT_SH_DOWN))
  {
    buttonStatus[BUTTONSTART] = 0;
    buttonStatus[BUTTONY]     = 0;
    buttonStatus[BUTTONDOWN]  = 0;
    buttonStatus[BUTTONHOME]  = 1;
  } 

  // Genesis 3-Button: Home Command (A + D-Up + Start)
  if((!gen_controller.sixButtonMode) && (currentGenesisState & SC_BTN_START ? 1:0) && (currentGenesisState & SC_BTN_A ? 1:0) && ((currentGenesisState & SC_BTN_UP) >> SC_BIT_SH_UP))
  {
    buttonStatus[BUTTONSTART]   = 0;
    buttonStatus[BUTTONY]       = 0;
    buttonStatus[BUTTONUP]      = 0;
    buttonStatus[BUTTONCAPTURE] = 1;
  }
}

void toggleControls()
{ 
  static unsigned long currentTime = 0;
  
  if(buttonStatus[BUTTONSELECT] && buttonStatus[BUTTONDOWN])
  {
     if(millis() - currentTime > toggleDelay)
     {
       if(!Swap_DPAD_JOY)
       {
        // Turn LEDs On
        Swap_DPAD_JOY = true;
        PORTD &= ~B00100000; // ON
       }
       else
       {
        // Turn LEDs Off
        Swap_DPAD_JOY = false;
        PORTD |= B00100000; // OFF
       }
       currentTime = millis();     
     }
  }
  else if(buttonStatus[BUTTONSELECT] && buttonStatus[BUTTONB])
  {
     if(millis() - currentTime > toggleDelay)
     {
       if(!Swap_Gen_Button)
       {
        // Turn LEDs On
        Swap_Gen_Button = true;
        PORTB &= ~B00000001; // ON
       }
       else
       {
        // Turn LEDs Off
        Swap_Gen_Button = false;
        PORTB |= B00000001; // OFF
       }
       currentTime = millis();     
     }
  }
  else
  {
    currentTime = millis();
  }
}


void processInputs()
{
  //D-Pad as Left Joystick
  if(Swap_DPAD_JOY == true)
  { 
    if      ((buttonStatus[BUTTONUP]) && (buttonStatus[BUTTONRIGHT]))     {ReportData.LX = 255; ReportData.LY = 000;}
    else if ((buttonStatus[BUTTONDOWN]) && (buttonStatus[BUTTONRIGHT]))   {ReportData.LX = 255; ReportData.LY = 255;} 
    else if ((buttonStatus[BUTTONDOWN]) && (buttonStatus[BUTTONLEFT]))    {ReportData.LX = 000; ReportData.LY = 255;}
    else if ((buttonStatus[BUTTONUP]) && (buttonStatus[BUTTONLEFT]))      {ReportData.LX = 000; ReportData.LY = 000;}
    else if (buttonStatus[BUTTONUP])                                      {ReportData.LX = 128; ReportData.LY = 000;}
    else if (buttonStatus[BUTTONDOWN])                                    {ReportData.LX = 128; ReportData.LY = 255;}
    else if (buttonStatus[BUTTONLEFT])                                    {ReportData.LX = 000; ReportData.LY = 128;}
    else if (buttonStatus[BUTTONRIGHT])                                   {ReportData.LX = 255; ReportData.LY = 128;}
    else                                                                  {ReportData.LX = 128; ReportData.LY = 128;}
    
    ReportData.HAT = DPAD_NOTHING_MASK_ON;
  }
  //D-Pad as Direction Pad (HAT)
  else
  {
    ReportData.LX = 128;
    ReportData.LY = 128;
    
    if      ((buttonStatus[BUTTONUP]) && (buttonStatus[BUTTONRIGHT]))     {ReportData.HAT = DPAD_UPRIGHT_MASK_ON;}
    else if ((buttonStatus[BUTTONDOWN]) && (buttonStatus[BUTTONRIGHT]))   {ReportData.HAT = DPAD_DOWNRIGHT_MASK_ON;} 
    else if ((buttonStatus[BUTTONDOWN]) && (buttonStatus[BUTTONLEFT]))    {ReportData.HAT = DPAD_DOWNLEFT_MASK_ON;}
    else if ((buttonStatus[BUTTONUP]) && (buttonStatus[BUTTONLEFT]))      {ReportData.HAT = DPAD_UPLEFT_MASK_ON;}
    else if (buttonStatus[BUTTONUP])                                      {ReportData.HAT = DPAD_UP_MASK_ON;}
    else if (buttonStatus[BUTTONDOWN])                                    {ReportData.HAT = DPAD_DOWN_MASK_ON;}
    else if (buttonStatus[BUTTONLEFT])                                    {ReportData.HAT = DPAD_LEFT_MASK_ON;}
    else if (buttonStatus[BUTTONRIGHT])                                   {ReportData.HAT = DPAD_RIGHT_MASK_ON;}
    else                                                                  {ReportData.HAT = DPAD_NOTHING_MASK_ON;}
  }
  
  ReportData.RX = RightX;
  ReportData.RY = RightY;

  if (buttonStatus[BUTTONA])            {ReportData.Button |= A_MASK_ON;}
  if (buttonStatus[BUTTONB])            {ReportData.Button |= B_MASK_ON;}
  if (buttonStatus[BUTTONX])            {ReportData.Button |= X_MASK_ON;}
  if (buttonStatus[BUTTONY])            {ReportData.Button |= Y_MASK_ON;}
  if (buttonStatus[BUTTONLB])           {ReportData.Button |= LB_MASK_ON;}
  if (buttonStatus[BUTTONRB])           {ReportData.Button |= RB_MASK_ON;}
  if (buttonStatus[BUTTONLT])           {ReportData.Button |= ZL_MASK_ON;}
  if (buttonStatus[BUTTONRT])           {ReportData.Button |= ZR_MASK_ON;}
  if (buttonStatus[BUTTONSTART])        {ReportData.Button |= START_MASK_ON;}
  if (buttonStatus[BUTTONSELECT])       {ReportData.Button |= SELECT_MASK_ON;}
  if (buttonStatus[BUTTONHOME])         {ReportData.Button |= HOME_MASK_ON;}
  if (buttonStatus[BUTTONCAPTURE])      {ReportData.Button |= CAPTURE_MASK_ON;}
  if (buttonStatus[BUTTONL3])           {ReportData.Button |= L3_MASK_ON;}
  if (buttonStatus[BUTTONR3])           {ReportData.Button |= R3_MASK_ON;}
}

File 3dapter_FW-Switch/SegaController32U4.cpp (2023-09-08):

//
// SegaController32U4.cpp
//
// Authors:
//       Jon Thysell <thysell@gmail.com>
//       Mikael Norrgård <mick@daemonbite.com>
//
// (Based on the code by Jon Thysell, but the interfacing is almost completely
//  rewritten by Mikael Norrgård)
//
// Copyright (c) 2017 Jon Thysell <http://jonthysell.com>
//
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
#include <EEPROM.h>

#include "Arduino.h"
#include "SegaController32U4.h"

// Value that triggers MiSTer mode if in EEPROM
static const char kMisterModeChar = 'M';

SegaController32U4::SegaController32U4(int eeprom_index)
    : _eeprom_index(eeprom_index)
{
    // Setup select pin as output high (7, PE6)
    DDR_SELECT  |= MASK_SELECT; // output
    PORT_SELECT |= MASK_SELECT; // high

    // Setup input pins (A0,A1,A2,A3,14,15 or PF7,PF6,PF5,PF4,PB3,PB1)
    DDRF  &= ~B00110000; // input
    PORTF |=  B00110000; // high to enable internal pull-up
    DDRB  &= ~B00001010; // input
    PORTB |=  B00001010; // high to enable internal pull-up
    DDRC  &= ~B01000000; // input
    PORTC |=  B01000000; // high to enable internal pull-up
    DDRD  &= ~B10000000; // input
    PORTD |=  B10000000; // high to enable internal pull-up   
    
    _inputReg1 = 0;
    _inputReg2 = 0;
    _inputReg3 = 0;
    _inputReg4 = 0;
    _currentState = 0;
    _previousState = 0;
    _misterMode = (EEPROM.read(_eeprom_index) == kMisterModeChar);
    _connected = 0;
    sixButtonMode = false;
    _ignoreCycles = 0;
    _pinSelect = true;
}

void SegaController32U4::toggleMisterMode() {
  _misterMode = !_misterMode;
  const char value = _misterMode ? kMisterModeChar : 0;
  EEPROM.write(_eeprom_index, value);
}

bool SegaController32U4::isMisterMode() {
    return _misterMode;
}

// Takes a state and swap btn_1 and btn_2
static void doSwapbuttons(word *state, int btn_1, int btn_2) {
  const bool one_is_set = (*state) & btn_1;
  const bool two_is_set = (*state) & btn_2;
  // Flip bit polarity when the two buttons have different states
  if (one_is_set ^ two_is_set) {
    *state ^= btn_1 | btn_2;
  }
}


word SegaController32U4::updateState()
{
  // "Normal" Six button controller reading routine, done a bit differently in this project
  // Cycle  TH out  TR in  TL in  D3 in  D2 in  D1 in  D0 in
  // 0      LO      Start  A      0      0      Down   Up      
  // 1      HI      C      B      Right  Left   Down   Up
  // 2      LO      Start  A      0      0      Down   Up      (Check connected and read Start and A in this cycle)
  // 3      HI      C      B      Right  Left   Down   Up      (Read B, C and directions in this cycle)
  // 4      LO      Start  A      0      0      0      0       (Check for six button controller in this cycle)
  // 5      HI      C      B      Mode   X      Y      Z       (Read X,Y,Z and Mode in this cycle)    
  // 6      LO      ---    ---    ---    ---    ---    Home    (Home only for 8bitdo wireless gamepads)      
  // 7      HI      ---    ---    ---    ---    ---    ---    

  // Set the select pin low/high
  _pinSelect = !_pinSelect;
  (!_pinSelect) ? PORT_SELECT &= ~MASK_SELECT : PORT_SELECT |= MASK_SELECT; // Set LOW on even cycle, HIGH on uneven cycle

  // Short delay to stabilise outputs in controller
  delayMicroseconds(SC_CYCLE_DELAY);

  // Read input register(s)
  _inputReg1 = PINF;
  _inputReg2 = PINB;
  _inputReg3 = PINC;
  _inputReg4 = PIND;

  if(_ignoreCycles <= 0)
  {
    if(_pinSelect) // Select pin is HIGH
    {
      if(_connected)
      {
        // Check if six button mode is active
        if(sixButtonMode)
        {
          // Read input pins for X, Y, Z, Mode
          (bitRead(_inputReg3, DB9_PIN1_BIT) == LOW) ? _currentState |= SC_BTN_Z : _currentState &= ~SC_BTN_Z;
          (bitRead(_inputReg4, DB9_PIN2_BIT) == LOW) ? _currentState |= SC_BTN_Y : _currentState &= ~SC_BTN_Y;
          (bitRead(_inputReg1, DB9_PIN3_BIT) == LOW) ? _currentState |= SC_BTN_X : _currentState &= ~SC_BTN_X;
          (bitRead(_inputReg1, DB9_PIN4_BIT) == LOW) ? _currentState |= SC_BTN_MODE : _currentState &= ~SC_BTN_MODE;
          sixButtonMode = false;
          _ignoreCycles = 2; // Ignore the two next cycles (cycles 6 and 7 in table above)
        }
        else
        {
          // Read input pins for Up, Down, Left, Right, B, C
          (bitRead(_inputReg3, DB9_PIN1_BIT) == LOW) ? _currentState |= SC_BTN_UP : _currentState &= ~SC_BTN_UP;
          (bitRead(_inputReg4, DB9_PIN2_BIT) == LOW) ? _currentState |= SC_BTN_DOWN : _currentState &= ~SC_BTN_DOWN;
          (bitRead(_inputReg1, DB9_PIN3_BIT) == LOW) ? _currentState |= SC_BTN_LEFT : _currentState &= ~SC_BTN_LEFT;
          (bitRead(_inputReg1, DB9_PIN4_BIT) == LOW) ? _currentState |= SC_BTN_RIGHT : _currentState &= ~SC_BTN_RIGHT;
          (bitRead(_inputReg2, DB9_PIN6_BIT) == LOW) ? _currentState |= SC_BTN_B : _currentState &= ~SC_BTN_B;
          (bitRead(_inputReg2, DB9_PIN9_BIT) == LOW) ? _currentState |= SC_BTN_C : _currentState &= ~SC_BTN_C;
        }
      }
      else // No Mega Drive controller is connected, use SMS/Atari mode
      {
        // Clear current state
        _currentState = 0;
        
        // Read input pins for Up, Down, Left, Right, Fire1, Fire2
        if (bitRead(_inputReg3, DB9_PIN1_BIT) == LOW) { _currentState |= SC_BTN_UP; }
        if (bitRead(_inputReg4, DB9_PIN2_BIT) == LOW) { _currentState |= SC_BTN_DOWN; }
        if (bitRead(_inputReg1, DB9_PIN3_BIT) == LOW) { _currentState |= SC_BTN_LEFT; }
        if (bitRead(_inputReg1, DB9_PIN4_BIT) == LOW) { _currentState |= SC_BTN_RIGHT; }
        if (bitRead(_inputReg2, DB9_PIN6_BIT) == LOW) { _currentState |= SC_BTN_A; }
        if (bitRead(_inputReg2, DB9_PIN9_BIT) == LOW) { _currentState |= SC_BTN_B; }
      }
    }
    else // Select pin is LOW
    {
      // Check if a controller is connected
      _connected = (bitRead(_inputReg1, DB9_PIN3_BIT) == LOW && bitRead(_inputReg1, DB9_PIN4_BIT) == LOW);
      
      // Check for six button mode
      sixButtonMode = (bitRead(_inputReg3, DB9_PIN1_BIT) == LOW && bitRead(_inputReg4, DB9_PIN2_BIT) == LOW);
      
      // Read input pins for A and Start 
      if(_connected)
      {
        if(!sixButtonMode)
        {
          (bitRead(_inputReg2, DB9_PIN6_BIT) == LOW) ? _currentState |= SC_BTN_A : _currentState &= ~SC_BTN_A;
          (bitRead(_inputReg2, DB9_PIN9_BIT) == LOW) ? _currentState |= SC_BTN_START : _currentState &= ~SC_BTN_START; 
        }
      }
    }
  }
  else
  {
    if(_ignoreCycles-- == 2) // Decrease the ignore cycles counter and read 8bitdo home in first "ignored" cycle, this cycle is unused on normal 6-button controllers
    {
      (bitRead(_inputReg3, DB9_PIN1_BIT) == LOW) ? _currentState |= SC_BTN_HOME : _currentState &= ~SC_BTN_HOME;
    }
  }

  return _currentState;
}

word SegaController32U4::getFinalState() {
#ifdef DEBUG
  if ((_previousState == SC_BTN_HOME) && (_currentState == (SC_BTN_HOME | SC_BTN_C))) {
    Serial.print("Read value from EEPROM:");
    Serial.println(isMisterMode());
  }
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

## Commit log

2021-08-18 Fix 6-button controller issue
    [SegaController32U4.h]
2021-08-18 Updating Readme and Button Layouts
2021-08-20 Aligned Genesis Buttons to NES/SNES
2021-08-22 Added initial KiCad PCB Project / Outputs
    [Triple Controller-B_Cu.gbr, Triple Controller-B_Mask.gbr, Triple Controller-Edge_Cuts.gbr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]
2021-09-08 Add files via upload
    Complete revamp of PCB due to incorrect pin layout
    [Triple Controller-B_Cu.gbr, Triple Controller-B_Mask.gbr, Triple Controller-Edge_Cuts.gbr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]
2021-10-06 Resolve Issue with SNES to Genesis Mapping
    Reordered buttons for Genesis for zero reconfig mapping
    [SegaController32U4.h]
2021-10-11 Added 3D Model Files
    3D STL and STEP files - courtesy of Dinierto Designs
    [Triple Controller Adapter Bottom.step, Triple Controller Adapter Bottom.stl, Triple Controller Adapter Top.step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]
2021-10-12 Small case revision
    [Triple_Controller_Adapter_Bottom.stl, Triple_Controller_Adapter_Top.stl]
2021-10-29 New case revisions - added Sparkfun USB-C
    [Triple Controller Adapter Micro USB Bottom.stl, Triple Controller Adapter Micro USB Top.stl, Triple Controller Adapter Micro USB.step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]
2021-11-27 New Arduino Project to support SNES NTT Controller
2021-12-03 Adding initial V2 PCB Code
2021-12-03 Adding V2 PCB KiCad Project
    [Triple Controller V2-B_Cu.gbr, Triple Controller V2-B_Mask.gbr, Triple Controller V2-Edge_Cuts.gbr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]
2021-12-03 Bug fixes across all projects
    [SegaController32U4.cpp, SegaController32U4.h]
2021-12-27 New Experimental Firmware for V1 and V2 Boards
2022-01-19 Combined V1 and V2 together to V2.1 PCB
    [Triple Controller V2.kicad_pcb, Triple Controller V2.kicad_sch, Triple Controller V2.sch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]
2022-04-17 Remap Genesis Buttons
2022-09-11 Add Makefile to build and upload with arduino-cli
2022-09-11 Implement profiles for the Genesis controller
    The Genesis controller can now be in two different modes if using
    an 8bitdo controller.
    1. MiSTer mode
    - The home button sends "DOWN + MODE"
    (This is because no equivalent of the home button exists
    on the other controller ports and MiSTer require they button
    mapping to be the same on all three ports)
    - Buttons are swapped A with B and X with Y. This is such that the
    position of the buttons is consistent between SNES and Genesis.
    2. Normal mode
    The mode can be toggled with "HOME + Z". The current mode is saved
    in EEPROM and will therefore persist over power offs.
    [SegaController32U4.cpp, SegaController32U4.h]
2022-10-17 Fix Arduino Compiler Warning
    [SegaController32U4.cpp]
2022-12-28 Cleaning up 3D Case files
    [Triple Controller Adapter Micro USB Bottom.stl, Triple Controller Adapter Micro USB Top.stl, Triple Controller Adapter Micro USB.step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]
2022-12-28 Reorganized 3D Case files
    [Triple Controller Adapter Micro USB (33mm) Bottom.stl, Triple Controller Adapter Micro USB (33mm) Top.stl, Triple Controller Adapter Micro USB (33mm).step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]
2023-01-06 Add New Arduino Code for XInput Version
    Provides Analogue Pocket Dock compatibility (all 3 inputs share and appear as a single input)
2023-08-20 Rebrand project and add new files
    [3dapter - Micro USB (33mm) Bottom.stl, 3dapter - Micro USB (33mm) Top.stl, 3dapter - Micro USB (33mm).step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]
2023-09-16 Modified N64 value mapping logic
    Modified N64 value mapping logic to set condition to switch between N64 controller raw value and HID 8-bit max (-128 to +127)
